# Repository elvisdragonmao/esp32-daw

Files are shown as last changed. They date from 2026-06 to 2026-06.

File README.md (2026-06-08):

# Pocket DAW

Pocket DAW 是一台以 ESP32 WROVER 製作的可攜式硬體音序器與迷你數位音樂工作站。它把四軌 step sequencer、即時搖桿錄音、TFT 操作介面與 I2S 音訊輸出整合在同一個手持裝置中，讓使用者不需要接上電腦，也能快速建立 loop、切換音色、調整速度並進行即興演奏。

這個專案的重點不只是把功能塞進開發板，而是把「可以被演奏的介面」做成完整作品：ESP32 負責即時音訊與 UI 狀態更新，搖桿承擔導覽與音符輸入，外殼則透過 Fusion 360 建模與 3D 列印，讓螢幕、控制器、喇叭輸出與握持角度形成一致的操作體驗。

<p align="center">
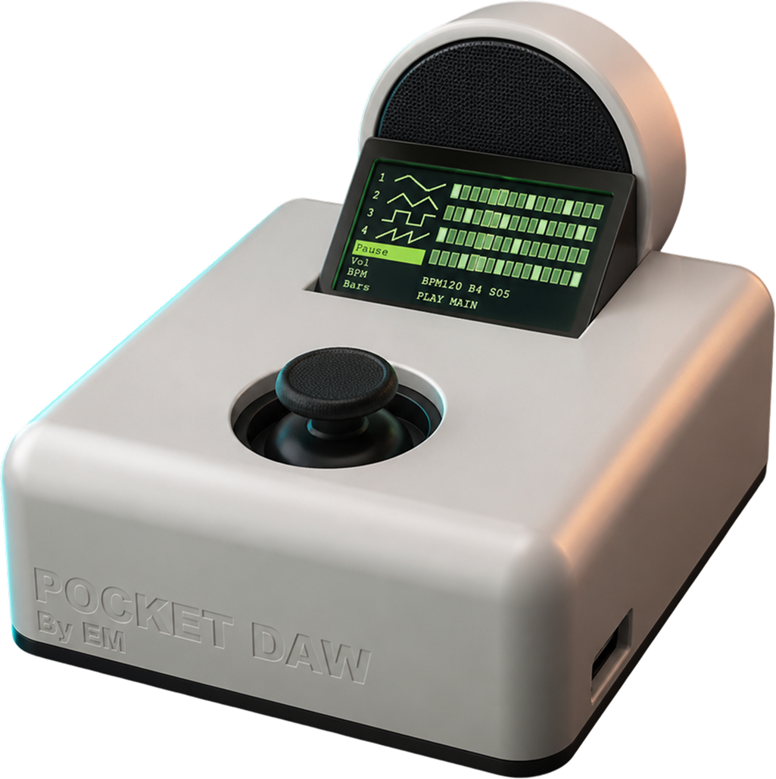
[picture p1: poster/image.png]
Pocket DAW 3D 列印外觀
  
</p>

## 專案亮點

- 四軌 step sequencer，每軌可獨立設定靜音、音量、音色與 pattern。
- 最長 32 steps，支援 1 到 8 小節 loop 長度，適合快速建立節奏與旋律片段。
- 以 2-axis analog joystick 操作所有選單，也能在錄音模式中輸入八方向音符。
- 內建 Sine、Triangle、Square、Saw 與 Drum voice，透過 MAX98357A 進行 I2S 音訊輸出。
- ST7735S TFT 顯示目前軌道、播放游標、step grid、BPM、Bars 與錄音狀態。
- 音訊、輸入與 UI 分成獨立 FreeRTOS tasks，音訊路徑使用固定 buffer，避免即時播放被畫面更新干擾。

## 畫面預覽

| 主畫面播放中 | 即時錄音中 |
| --- | --- |
| Pocket DAW 主畫面播放中 | Pocket DAW 即時錄音畫面 |

主畫面左側顯示四條軌道與主要功能，右側是 4 軌 step grid。亮色格代表該 step 有音符，白色框代表目前播放位置。錄音時，畫面會切換為 REC 狀態，只要在目前 step 期間推到搖桿方向，系統就會把該方向鎖存並寫入目前選取的軌道。

## 硬體規格

| 類別 | 規格 |
| --- | --- |
| 控制核心 | ESP32 WROVER Module |
| Arduino FQBN | `esp32:esp32:esp32wrover` |
| 顯示 | ST7735S 80 x 160 TFT |
| 音訊輸出 | MAX98357A I2S DAC / Class-D amplifier |
| 輸入 | 2-axis analog joystick with switch |
| 音訊取樣率 | 22.05 kHz |
| 軌道數 | 4 tracks |
| Pattern 長度 | 1-8 bars, 4 steps per bar, 32 steps max |

## 硬體連接

<p align="center">
  ESP32 WROVER、TFT、I2S amplifier 與搖桿接線圖
</p>

| 功能 | ESP32 pin |
| --- | --- |
| TFT CS | GPIO 5 |
| TFT DC | GPIO 27 |
| TFT RST | GPIO 33 |
| TFT MOSI | GPIO 23 |
| TFT SCLK | GPIO 18 |
| I2S BCLK | GPIO 26 |
| I2S LRC / WS | GPIO 25 |
| I2S DOUT | GPIO 22 |
| I2S SD | GPIO 21 |
| Joystick X | GPIO 34 |
| Joystick Y | GPIO 35 |
| Joystick SW | GPIO 32 |

## 操作方式

Pocket DAW 只使用搖桿完成導覽、確認、數值調整與錄音輸入。

| 搖桿動作 | 一般操作 |
| --- | --- |
| 上 / 下 | 移動選單游標，或增加 / 減少目前參數 |
| 右 | 進入選單、確認項目、切換播放 |
| 左 | 返回上一層，或離開參數調整畫面 |
| 按下 | 作為硬體按鍵輸入保留 |

錄音模式中，搖桿方向不再控制選單，而是映射成音符。整個 step 都沒有推到方向時，該格會錄成空拍。

| 搖桿方向 | 音符 |
| --- | --- |
| 左 | C |
| 上 | D |
| 右上 | E |
| 右 | F |
| 右下 | G |
| 下 | A |
| 左下 | B |
| 左上 | C+ |
| 整格無方向 | 空拍 |

如果目前軌道選擇 `Drum`，同一組方向會映射成 drum 聲音：左 / 右下是 Kick，上 / 下是 Snare，右上 / 左下是 Hat，右 / 左上是 Tom。

## 主畫面與選單

主畫面左側顯示 4 條軌道與主要控制項：

- `1` + sine 波形圖示
- `2` + triangle 波形圖示
- `3` + square 波形圖示
- `4` + saw 波形圖示
- `Play` / `Pause`
- `Vol`
- `BPM`
- `Bars`

選擇第 1 到第 4 軌後向右，可進入該軌道的設定選單。

| 項目 | 功能 |
| --- | --- |
| `Mute` / `Unmut` | 靜音或取消靜音目前軌道 |
| `Record` | 進入錄音待命 |
| `Vol` | 調整目前軌道音量 |
| `OSC` | 選擇目前軌道的 oscillator |

全域參數包含：

- `M Vol`：master volume，影響整體輸出音量。
- `TnVol`：單一軌道音量，只影響目前選取的軌道。
- `BPM`：sequencer 速度，每個 step 的時間是 `30000 / BPM` ms。
- `Bars`：loop 小節數，範圍是 1 到 8；每小節 4 step。

## Oscillator

每條軌道可以選擇一種 oscillator。

| 顯示 | 聲音 |
| --- | --- |
| Sine 圖示 | Sine |
| Triangle 圖示 | Triangle |
| Square 圖示 | Square |
| Saw 圖示 | Saw |
| `Drum` | Kick、Snare、Hat、Tom |

## 錄音流程

1. 在主畫面選擇想錄音的軌道。
2. 向右進入軌道選單。
3. 選擇 `Record` 並向右確認。
4. 畫面進入 `ARM`，系統等待 loop 回到 step 1。
5. 進入 `REC` 後，每個 step 期間只要推到搖桿方向就會鎖存該音符，切到下一格時寫入剛結束的 step。
6. 錄完整個 loop 後，自動回到軌道選單。

這個流程讓錄音起點固定在 loop 第一拍，避免每次按下錄音時因時機不同造成 pattern 位移。

## 快速開始

1. 確認 ST7735S、MAX98357A、搖桿與 ESP32 WROVER 已依照接線表連接。
2. 接上 USB，確認序列埠出現，例如 `/dev/cu.usbserial-0001`。
3. 編譯並上傳：

```sh
"/Applications/Arduino IDE.app/Contents/Resources/app/lib/backend/resources/arduino-cli" compile --upload --fqbn esp32:esp32:esp32wrover --port /dev/cu.usbserial-0001 .
```

上傳完成後，ESP32 會自動 reset 並進入主畫面。如果上傳卡在 `Connecting...`，按住板子上的 `BOOT` 鍵直到開始寫入 flash。

## 編譯與上傳

如果 `arduino-cli` 已經在 `PATH` 裡：

```sh
arduino-cli compile --fqbn esp32:esp32:esp32wrover .
```

這台 Mac 也可以直接使用 Arduino IDE 內建 CLI：

```sh
"/Applications/Arduino IDE.app/Contents/Resources/app/lib/backend/resources/arduino-cli" compile --fqbn esp32:esp32:esp32wrover .
```

列出目前連接的板子：

```sh
arduino-cli board list
```

上傳到 ESP32 WROVER：

```sh
arduino-cli compile --upload --fqbn esp32:esp32:esp32wrover --port /dev/cu.usbserial-0001 .
```

## 搖桿校正

目前搖桿原始 ADC 範圍設定在 `Config.h`：

```cpp
#define JOY_ADC_MIN 0
#define JOY_ADC_MAX 4095
#define JOY_NORM_SCALE 1000
#define JOY_NAV_DEAD 450
#define JOY_RECORD_DEAD 450
```

開機時會自動讀取搖桿當下的靜止位置作為中心點。執行時會把 ADC 數值限制在 `0..4095`，再轉成 `-1000..1000`，讓 dead zone 更容易調整。

如果搖桿太容易誤觸，優先調高：

- `JOY_NAV_DEAD`
- `JOY_RECORD_DEAD`

如果搖桿太不靈敏，則調低這兩個值。若某個方向完全無法觸發，應先檢查搖桿接線與供電，再調整軟體參數。

## 軟體架構

程式依功能拆成固定模組，避免把輸入、音訊、狀態與顯示邏輯混在同一個檔案。

| 檔案 | 說明 |
| --- | --- |
| `esp32-daw.ino` | Arduino 入口、初始化順序、FreeRTOS task 建立 |
| `Config.h` | pin、畫面尺寸、音訊參數、搖桿設定 |
| `Types.h` | enum 與固定大小 struct |
| `State.h/.cpp` | 共享狀態、dirty flags、初始化 pattern |
| `Joystick.h/.cpp` | ADC 校正、濾波、dead zone、方向判斷 |
| `AudioEngine.h/.cpp` | I2S、oscillator、envelope、mixing、audio task |
| `Sequencer.h/.cpp` | step 推進、錄音寫入、voice trigger |
| `DisplayUI.h/.cpp` | TFT 繪圖與 dirty UI 更新 |
| `InputController.h/.cpp` | 搖桿事件、debounce、選單狀態機 |

## 即時音訊設計

音訊路徑維持固定且可預期：

- 使用固定大小陣列與固定大小 audio buffer。
- 不在 runtime path 使用 `new`、`malloc`、`free`、STL containers 或 Arduino `String`。
- audio path 不使用 virtual function。
- critical section 只做短時間共享狀態讀寫，渲染前先複製必要資料。
- audio task pinned to core 1，priority 高於 input / UI task。
- UI 使用 dirty flags，只更新需要重繪的區域，避免頻繁全畫面刷新。

## 畫面顏色

如果實機 ST7735S 出現橘色顯示成藍色、亮藍色顯示成土黃色，代表 TFT 的 RGB / BGR 色序需要在 firmware 裡修正。海報用 SVG 保持預期 UI 顏色，不需要用紅藍交換補償。

## 海報與 UI 素材

海報與 UI 素材位於 `poster/`：

- `poster/report.html`：A2 海報版面。
- `poster/report.css`：海報樣式。
- `poster/image.png`：產品外觀圖。
- `poster/circuit.svg`：硬體接線圖。
- `poster/ui-svg/`：TFT UI 狀態圖。

重新產生 UI SVG：

```sh
python3 tools/generate_ui_svgs.py
```

SVG 使用 `viewBox="0 24 160 80"` 對齊 Arduino 程式中的 TFT 可見區域，並使用內縮像素線模擬 `Adafruit_GFX::drawRect()`，避免右側邊框在設計軟體中被裁切。

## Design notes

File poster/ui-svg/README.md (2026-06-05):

# UI SVG Exports

Poster-ready SVG recreations of the current TFT UI states.

Generated by `tools/generate_ui_svgs.py`.

Each SVG uses `viewBox="0 24 160 80"` to match the TFT visible area.
Colors represent the intended firmware UI colors without red/blue compensation.

- `01-main-stopped.svg`: Main Stopped
- `02-main-playing.svg`: Main Playing
- `03-track-menu.svg`: Track Menu
- `04-master-volume.svg`: Master Volume
- `05-track-volume.svg`: Track Volume
- `06-bpm.svg`: BPM
- `07-bars.svg`: Bars
- `08-osc-menu.svg`: OSC Menu
- `09-record-armed.svg`: Record Armed
- `10-recording.svg`: Recording

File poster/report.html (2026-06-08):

Digital Design & Fabrication / Embedded Music Instrument

# Pocket DAW

手掌大小的可攜式硬體音樂工作站

Pocket DAW 是一台迷你硬體編曲工具，目標是把 groovebox 與數位音樂工作站中最核心的 loop、step sequencer、音色切換與即時錄音，縮進一個能隨身攜帶、單手操作的裝置。 它不追求完整取代桌面 DAW，而是重新設計「拿起來就能玩音樂」的最小介面： 使用者只透過一個黑色類 Arduino 搖桿、一片小型 TFT 螢幕與內建喇叭， 就能完成四軌節奏與旋律的即興編排。

Fusion 360 3D Print ESP32 WROVER I2S Audio

Pocket DAW enclosure render with TFT screen and joystick

Tracks 4

可分配 drum、bass、lead 與 texture

Pattern 32

32-step loop，支援即時寫入與播放

Display 160 × 80

ST7735S TFT 顯示軌道、游標與參數

Input 1

單一搖桿完成導覽、確認與音符輸入

01

## 設計動機與目標

一般實體合成器、groovebox 或編曲機雖然能帶來直接的演奏手感， 但往往價格高、體積大，也需要大量旋鈕、按鍵與學習成本。 本作品從「我想把可以隨時玩音樂的工具放進包包裡」出發， 嘗試設計一台介於玩具、樂器與音樂工作站之間的迷你裝置。

- 將硬體音樂工作站的核心流程濃縮為四軌 loop 編曲。
- 以單一搖桿取代大量旋鈕與按鍵，降低控制介面複雜度。
- 透過小螢幕提供即時回饋，讓使用者能邊看邊錄、邊聽邊改。
- 以 3D 列印外殼整合螢幕、搖桿、喇叭與電子模組，形成可手持的完整原型。

02

## 案例與情境分析

本作品參考了幾種不同音樂硬體的設計方向：Arturia MicroFreak 將小尺寸、 sequencer 與多樣聲音引擎結合，代表「高密度控制」；Expressive E Osmose 與 Touché 則強調手勢與聲音表情之間的直接連結；CHOMPI 的 screenless workflow、 RGB 回饋與可攜外形，則顯示音樂工具也可以像玩具一樣直覺、輕鬆。

Pocket DAW 並未直接複製這些產品的控制器數量，而是把它們的共同精神轉化成更小的問題： 如果只剩下一個搖桿，還能不能完成選軌、調參、輸入音符與即時錄音？ 因此，本作品的情境設定是通勤、宿舍、展場或課堂之間的碎片時間， 使用者不需要打開電腦，也能用手掌大小的裝置快速建立一段 loop。

03

## 介面與操作流程

Main playing screen of the Pocket DAW UI

主畫面集中顯示四軌狀態、step grid、播放游標與錄音提示，讓演奏時不必頻繁切換頁面。

Track menu screen

Track

BPM screen

BPM

Oscillator menu screen

OSC

Recording screen

REC

04

## 單搖桿互動設計

### Navigation

搖桿上、下用於移動游標或調整數值；右方向負責確認、進入選單與播放切換； 左方向則回到上一層。這套規則讓使用者能以拇指完成主要操作。

### Recording

啟動錄音後，系統會等待 loop 回到第一拍，再於每個 step 讀取搖桿方向。 八個方向對應不同音高，沒有有效方向時則保留休止，形成簡化但可演奏的輸入方式。

C D E F G A B C+

05

## 材質、機構與組裝

外殼以 3D 列印成形，造型分為白色外框、深色操作面板與傾斜螢幕區。 中央配置黑色類 Arduino 搖桿，讓拇指自然落在主要控制點；螢幕設於前方斜面， 使使用者手持時仍能直接讀取播放狀態；喇叭則安排在後側，避免被手掌完全遮蔽。

機構設計以實際模組尺寸為基準，先確認 TFT、搖桿、ESP32、MAX98357A、 小喇叭與走線空間，再回推外殼厚度、面板開孔與內部固定位置。 這使外觀不只是包覆電子零件，而是同時服務握持、觀看、演奏與維修。

06

## 系統架構與硬體連接

Joystick Input State Sequencer Audio Engine I2S Amp Speaker

Circuit wiring diagram for ESP32 mini DAW

ESP32 負責搖桿輸入、TFT 顯示與音序器狀態；MAX98357A 透過 I2S 接收音訊資料， 再推動內建小喇叭輸出聲音。

07

## 設計呈現與核心規格

海報以渲染模擬圖呈現最終外觀，包括白色外殼、黑色搖桿、斜面螢幕與後置喇叭配置； 工程視圖則以電路接線圖與 UI 狀態圖補充內部系統。兩者分別說明產品的外部使用情境與內部實作邏輯。

控制核心

ESP32 WROVER, FreeRTOS tasks

音訊輸出

MAX98357A I2S DAC / Class-D amplifier

顯示模組

ST7735S TFT, 160 × 80 display UI

輸入方式

2-axis analog joystick + push switch

聲音與節奏

4 tracks, 32 steps, BPM, volume, waveform control

毛宥鈞 設計・製作 資訊工程學系 / 114550020

ESP32-DAW / A2 REPORT / 2026

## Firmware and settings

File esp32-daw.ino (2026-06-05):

#include <Arduino.h>

#include "AudioEngine.h"
#include "DisplayUI.h"
#include "InputController.h"
#include "Joystick.h"
#include "State.h"

static void clearDirtyFlags() {
  for (uint8_t s = 0; s < STEP_COUNT; s++) {
    dirtyCol[s] = false;
  }

  for (uint8_t t = 0; t < TRACK_COUNT; t++) {
    for (uint8_t s = 0; s < STEP_COUNT; s++) {
      dirtyCell[t][s] = false;
    }
  }
}

void setup() {
  Serial.begin(115200);
  delay(1000);
  Serial.println("BOOT 1");

  Serial.println("BOOT 2 joystick");
  joystick.begin();

  Serial.println("BOOT 3 data");
  initSineTable();
  initTracks();
  clearDirtyFlags();

  Serial.println("BOOT 4 display");
  displayUI.begin();

  Serial.println("BOOT 5 I2S");
  audioEngine.begin();

  Serial.println("BOOT 6 tasks");

  xTaskCreatePinnedToCore(audioTask, "audioTask", 8192, NULL, 3, NULL, 1);
  xTaskCreatePinnedToCore(inputTask, "inputTask", 4096, NULL, 2, NULL, 0);
  xTaskCreatePinnedToCore(uiTask, "uiTask", 8192, NULL, 1, NULL, 0);

  Serial.println("BOOT DONE");
}

void loop() {
  vTaskDelay(1000 / portTICK_PERIOD_MS);
}

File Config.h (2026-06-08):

#ifndef CONFIG_H
#define CONFIG_H

// ============================================================
// Pin settings
// ============================================================

// ST7735S 80x160 TFT
#define PIN_TFT_CS 5
#define PIN_TFT_DC 27
#define PIN_TFT_RST 33
#define PIN_TFT_MOSI 23
#define PIN_TFT_SCLK 18
#define TFT_ROTATION 1
#define TFT_USE_BGR_COLOR_ORDER 1

// MAX98357A
#define PIN_I2S_BCLK 26
#define PIN_I2S_LRC 25
#define PIN_I2S_DOUT 22
#define PIN_I2S_SD 21

// Joystick
#define PIN_JOY_X 34
#define PIN_JOY_Y 35
#define PIN_JOY_SW 32

// Common joystick modules report a smaller Y value when pushed up.
#define JOY_INVERT_X false
#define JOY_INVERT_Y true

// Joystick anti-noise tuning
#define JOY_ADC_MIN 0
#define JOY_ADC_MAX 4095
#define JOY_NORM_SCALE 1000
#define JOY_ANALOG_SAMPLES 4
#define JOY_FILTER_WEIGHT 4
#define JOY_NAV_DEAD 450
#define JOY_RECORD_DEAD 450
#define JOY_AXIS_MARGIN 120
#define JOY_DIR_STABLE_MS 45
#define JOY_REC_STABLE_MS 40

// ============================================================
// Audio settings
// ============================================================

#define SAMPLE_RATE 22050
#define AUDIO_FRAMES 128

// ============================================================
// Sequencer settings
// ============================================================

#define TRACK_COUNT 4
#define STEPS_PER_BAR 4
#define MIN_BAR_COUNT 1
#define DEFAULT_BAR_COUNT 4
#define MAX_BAR_COUNT 8
#define STEP_COUNT (MAX_BAR_COUNT * STEPS_PER_BAR)

// The active loop length is barCount * STEPS_PER_BAR.
// stepMs = 30000 / BPM

// ============================================================
// Display layout: 160x80 landscape
// ============================================================

#define SCREEN_W             160
#define SCREEN_H             80

// 24 ~ 103
#define VIEW_X               0
#define VIEW_Y               24
#define VIEW_W               160
#define VIEW_H               80

#define MENU_W               44

#define GRID_X               (VIEW_X + 47)
#define GRID_Y               (VIEW_Y + 3)

#define CELL_W               7
#define CELL_H               9
#define ROW_H                13

#define STATUS_Y             (VIEW_Y + 56)
#define STATUS_H             24

#endif

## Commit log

2026-06-05 joystick: enhance anti-noise tuning and calibration logic
2026-06-05 joystick: enhance joystick calibration and normalization logic
2026-06-05 oscillator: add drum voice and waveform icons
    [AudioEngine.cpp]
2026-06-07 poster: poster & image
    [circruit.fzz]
2026-06-07 esp32-daw: rename
